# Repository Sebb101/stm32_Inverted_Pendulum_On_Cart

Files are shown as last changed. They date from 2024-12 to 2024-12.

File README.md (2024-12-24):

# Stm32_Inverted_Pendulum_On_Cart
Control systems learning project

Classic controls project: Inverted Pendulum On a Cart

Designed a custom stm32 board to handle data acquisition, motor control, and data out.

Tuned PID constants using matlab's System Identification and PID tuner applications

3D printed motor, encoder mounts, rail fixture and cart.

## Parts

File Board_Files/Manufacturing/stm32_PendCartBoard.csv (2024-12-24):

Source: | C:\Users\jasev\OneDrive\Desktop\KiCad Designs\KiCad_Personal\stm32_PendCartBoard\stm32_PendCartBoard.kicad_sch
Date: | 6/3/2023 7:27:07 PM
Tool: | Eeschema (6.0.11)
Generator: | C:\Program Files\KiCad\6.0\bin\scripting\plugins/bom_csv_grouped_by_value_with_fp.py
Component Count: | 45
Ref | Qnty | Value | Cmp name | Footprint | Description | Vendor
C1, C2, | 2 | 22u | C | Capacitor_SMD:C_0805_2012Metric | Unpolarized capacitor
C3, | 1 | 10u | C | Capacitor_SMD:C_0603_1608Metric | Unpolarized capacitor
C4, C5, C6, C7, C11, | 5 | 100n | C | Capacitor_SMD:C_0402_1005Metric | Unpolarized capacitor
C8, | 1 | 10n | C | Capacitor_SMD:C_0402_1005Metric | Unpolarized capacitor
C9, C10, | 2 | 1u | C | Capacitor_SMD:C_0402_1005Metric | Unpolarized capacitor
C12, C13, | 2 | 10p | C | Capacitor_SMD:C_0402_1005Metric | Unpolarized capacitor
C14, C16, | 2 | 0.1u | C | Capacitor_SMD:C_0805_2012Metric | Unpolarized capacitor
C15, C17, | 2 | 10u | C | Capacitor_SMD:C_0805_2012Metric | Unpolarized capacitor
D1, | 1 | RED | LED | LED_SMD:LED_0603_1608Metric | Light emitting diode
D2, | 1 | BLUE | LED | LED_SMD:LED_0603_1608Metric | Light emitting diode
FB1, | 1 | 120R | FerriteBead | Inductor_SMD:L_0603_1608Metric | Ferrite bead
H1, H2, H3, H4, | 4 | MountingHole | MountingHole | MountingHole:MountingHole_2.2mm_M2 | Mounting Hole without connection
J1, | 1 | PWR | Conn_01x02_Male | Connector_PinHeader_2.54mm:PinHeader_1x02_P2.54mm_Vertical | Generic connector, single row, 01x02, script generated (kicad-library-utils/schlib/autogen/connector/)
J2, | 1 | GPIO | Conn_01x04_Male | Connector_PinHeader_2.54mm:PinHeader_1x04_P2.54mm_Vertical | Generic connector, single row, 01x04, script generated (kicad-library-utils/schlib/autogen/connector/)
J3, | 1 | USB_B_Micro | USB_B_Micro | Connector_USB:USB_Micro-B_Wuerth_629105150521 | USB Micro Type B connector
J4, | 1 | MotorOut | Conn_01x04_Male | Connector_PinHeader_2.54mm:PinHeader_1x04_P2.54mm_Vertical | Generic connector, single row, 01x04, script generated (kicad-library-utils/schlib/autogen/connector/)
J5, | 1 | DEBUG | Conn_01x02_Male | Connector_PinHeader_2.54mm:PinHeader_1x02_P2.54mm_Vertical | Generic connector, single row, 01x02, script generated (kicad-library-utils/schlib/autogen/connector/)
J6, | 1 | 5Vin | Conn_01x02_Male | Connector_PinHeader_2.54mm:PinHeader_1x02_P2.54mm_Vertical | Generic connector, single row, 01x02, script generated (kicad-library-utils/schlib/autogen/connector/)
J7, | 1 | BAT 12V+ | Conn_01x02_Male | Connector_PinHeader_2.54mm:PinHeader_1x02_P2.54mm_Vertical | Generic connector, single row, 01x02, script generated (kicad-library-utils/schlib/autogen/connector/)
J8, | 1 | UART | Conn_01x04_Male | Connector_PinHeader_2.54mm:PinHeader_1x04_P2.54mm_Vertical | Generic connector, single row, 01x04, script generated (kicad-library-utils/schlib/autogen/connector/)
J9, | 1 | I2C | Conn_01x04_Male | Connector_PinHeader_2.54mm:PinHeader_1x04_P2.54mm_Vertical | Generic connector, single row, 01x04, script generated (kicad-library-utils/schlib/autogen/connector/)
J10, | 1 | PWR | Conn_01x04_Male | Connector_PinHeader_2.54mm:PinHeader_1x04_P2.54mm_Vertical | Generic connector, single row, 01x04, script generated (kicad-library-utils/schlib/autogen/connector/)
R1, R3, R4, R5, R6, | 5 | 1k5 | R | Resistor_SMD:R_0402_1005Metric | Resistor
R2, | 1 | 10k | R | Resistor_SMD:R_0402_1005Metric | Resistor
SW1, | 1 | SW_SPDT | SW_SPDT | Button_Switch_SMD:SW_SPDT_PCM12 | Switch, single pole double throw
U1, | 1 | AMS1117-3.3 | AMS1117-3.3 | Package_TO_SOT_SMD:SOT-223-3_TabPin2 | 1A Low Dropout regulator, positive, 3.3V fixed output, SOT-223
U2, | 1 | STM32F103C8T6 | STM32F103C8Tx | Package_QFP:LQFP-48_7x7mm_P0.5mm | ARM Cortex-M3 MCU, 64KB flash, 20KB RAM, 72MHz, 2-3.6V, 37 GPIO, LQFP-48
U3, | 1 | TB6612FNG | TB6612FNG | Package_SO:SSOP-24_5.3x8.2mm_P0.65mm | Driver IC for Dual DC motor, SSOP-24
Y1, | 1 | 16MHz | Crystal_GND24 | Crystal:Crystal_SMD_3225-4Pin_3.2x2.5mm | Four pin crystal, GND on pins 2 and 4

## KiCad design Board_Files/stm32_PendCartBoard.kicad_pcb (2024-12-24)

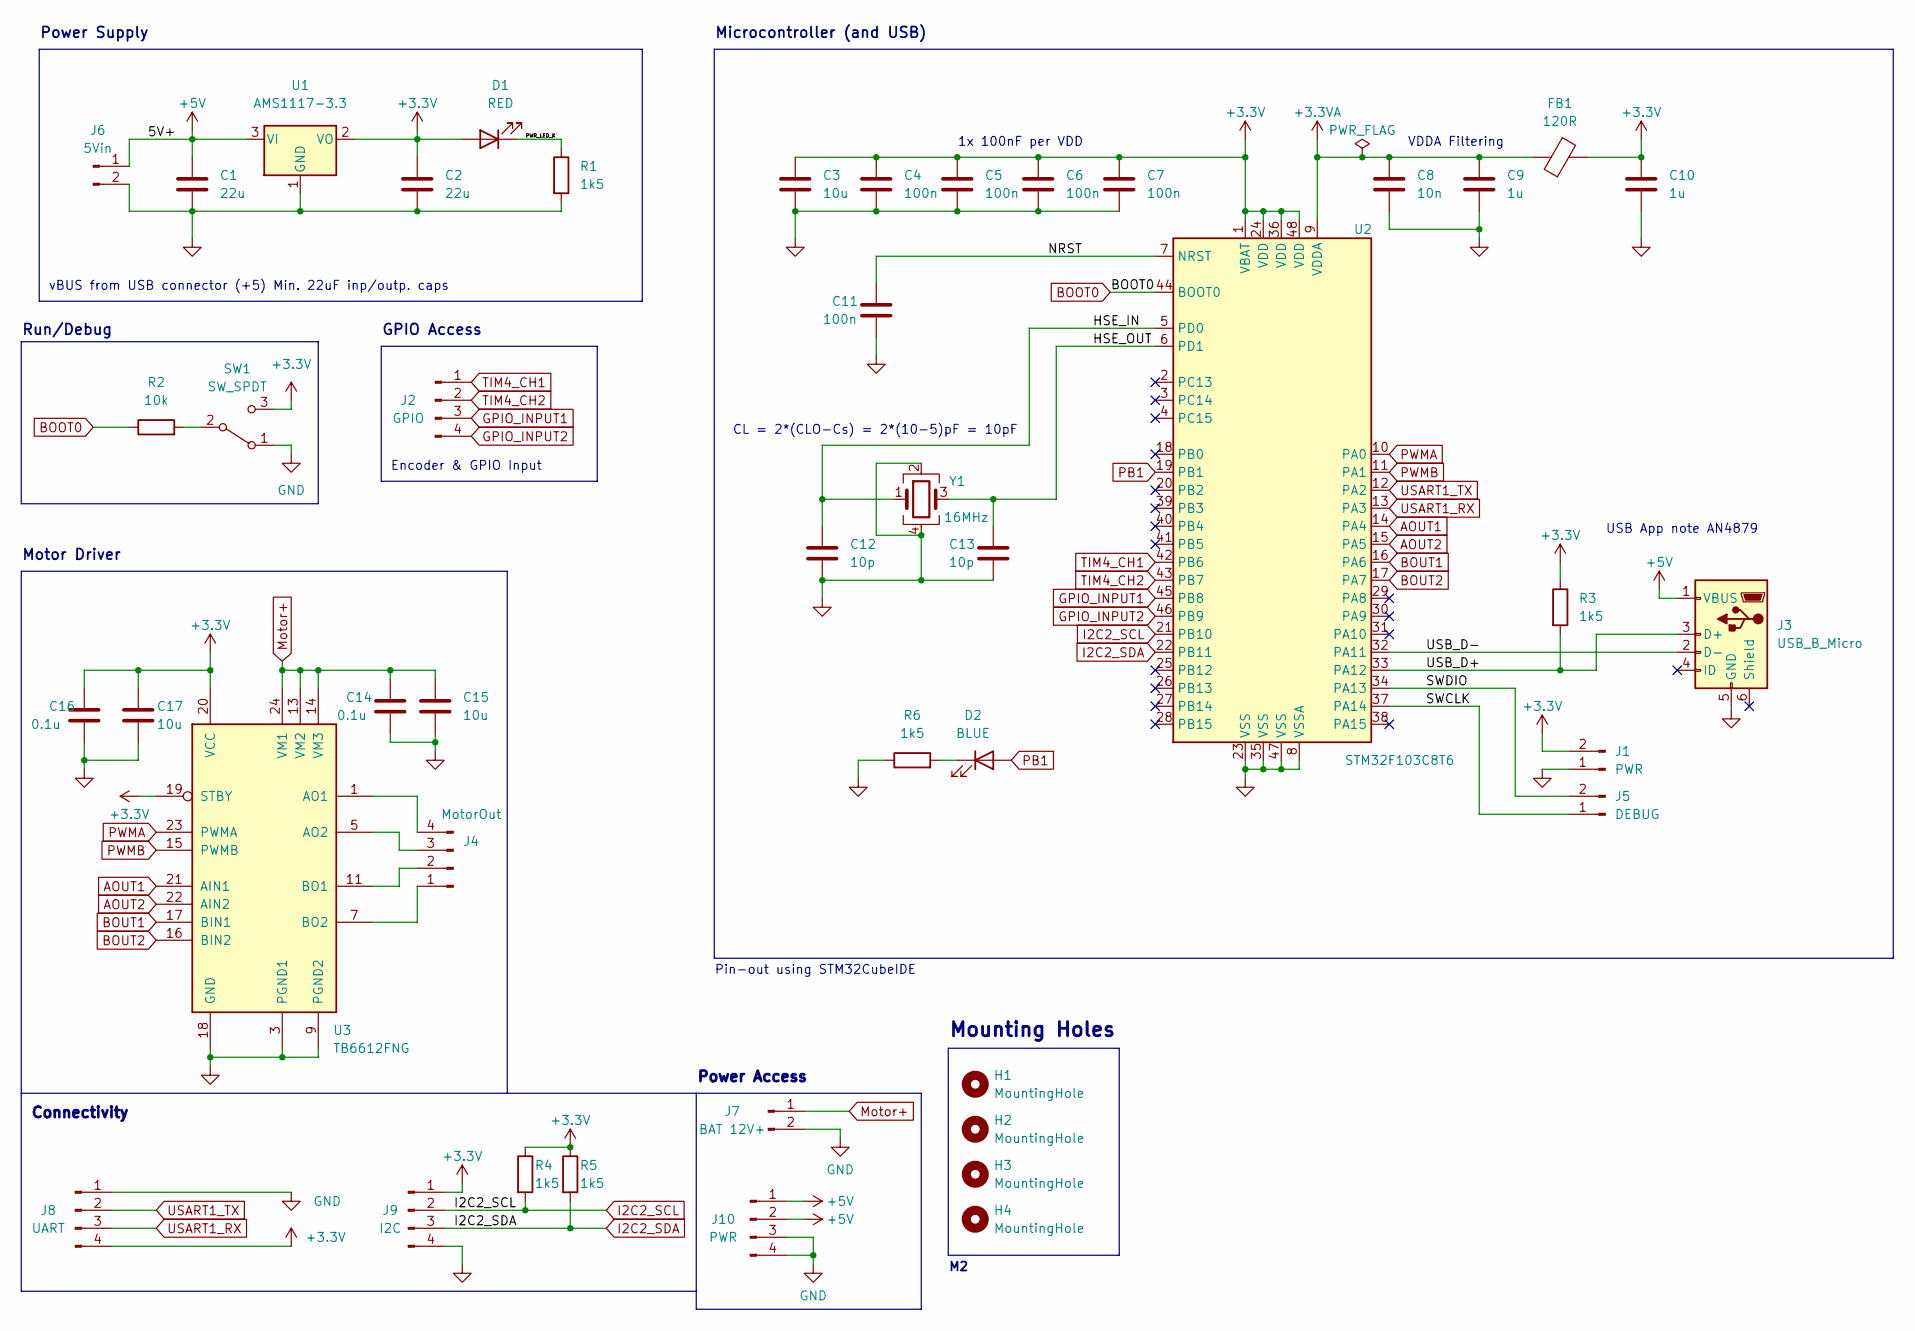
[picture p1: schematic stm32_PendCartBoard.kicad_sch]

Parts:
C1, C2: 22u; C_0805_2012Metric
C3: 10u; C_0603_1608Metric
C4, C5, C6, C7, C11: 100n; C_0402_1005Metric
C8: 10n; C_0402_1005Metric
C9, C10: 1u; C_0402_1005Metric
C12, C13: 10p; C_0402_1005Metric
C14, C16: 0.1u; C_0805_2012Metric
C15, C17: 10u; C_0805_2012Metric
D1: RED; LED_0603_1608Metric
D2: BLUE; LED_0603_1608Metric
FB1: 120R; L_0603_1608Metric
H1, H2, H3, H4: MountingHole; MountingHole_2.2mm_M2
J1: PWR; PinHeader_1x02_P2.54mm_Vertical
J2: GPIO; PinHeader_1x04_P2.54mm_Vertical
J3: USB_B_Micro; USB_Micro-B_Wuerth_629105150521
J4: MotorOut; PinHeader_1x04_P2.54mm_Vertical
J5: DEBUG; PinHeader_1x02_P2.54mm_Vertical
J6: 5Vin; PinHeader_1x02_P2.54mm_Vertical
J7: BAT 12V+; PinHeader_1x02_P2.54mm_Vertical
J8: UART; PinHeader_1x04_P2.54mm_Vertical
J9: I2C; PinHeader_1x04_P2.54mm_Vertical
J10: PWR; PinHeader_1x04_P2.54mm_Vertical
R1, R3, R4, R5, R6: 1k5; R_0402_1005Metric
R2: 10k; R_0402_1005Metric
SW1: SW_SPDT; SW_SPDT_PCM12
U1: AMS1117-3.3; SOT-223-3_TabPin2
U2: STM32F103C8T6; LQFP-48_7x7mm_P0.5mm
U3: TB6612FNG; SSOP-24_5.3x8.2mm_P0.65mm
Y1: 16MHz; Crystal_SMD_3225-4Pin_3.2x2.5mm

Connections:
+3.3V: C2.1, C3.1, C4.1, C5.1, C6.1, C7.1, C10.1, C16.1, C17.1, D1.2 (A), FB1.2, J1.2, J8.4, J9.1, R3.1, R4.1, R5.1, SW1.3 (C), U1.2 (VO), U2.1 (VBAT), U2.24 (VDD), U2.36 (VDD), U2.48 (VDD), U3.19 (STBY), U3.20 (VCC)
+3.3VA: C8.1, C9.1, FB1.1, U2.9 (VDDA)
+5V: C1.1, J3.1 (VBUS), J6.1, J10.1, J10.2, U1.3 (VI)
/HSE_IN: C12.1, U2.5 (PD0), Y1.1
/HSE_OUT: C13.1, U2.6 (PD1), Y1.3
/NRST: C11.1, U2.7 (NRST)
/PWR_LED_K: D1.1 (K), R1.1
/SWCLK: J5.1, U2.37 (PA14)
/SWDIO: J5.2, U2.34 (PA13)
/USB_D+: J3.3 (D+), R3.2, U2.33 (PA12)
/USB_D-: J3.2 (D-), U2.32 (PA11)
AOUT1: U2.14 (PA4), U3.21 (AIN1)
AOUT2: U2.15 (PA5), U3.22 (AIN2)
BOOT0: R2.1, U2.44 (BOOT0)
BOUT1: U2.16 (PA6), U3.17 (BIN1)
BOUT2: U2.17 (PA7), U3.16 (BIN2)
GND: C1.2, C2.2, C3.2, C4.2, C5.2, C6.2, C7.2, C8.2, C9.2, C10.2, C11.2, C12.2, C13.2, C14.2, C15.2, C16.2, C17.2, J1.1, J3.5 (GND), J6.2, J7.2, J8.1, J9.4, J10.3, J10.4, R1.2, R6.1, SW1.1 (A), U1.1 (GND), U2.8 (VSSA), U2.23 (VSS), U2.35 (VSS), U2.47 (VSS), U3.3 (PGND1), U3.4 (PGND1), U3.9 (PGND2), U3.10 (PGND2), U3.18 (GND), Y1.2, Y1.4
GPIO_INPUT1: J2.3, U2.45 (PB8)
GPIO_INPUT2: J2.4, U2.46 (PB9)
I2C2_SCL: J9.2, R4.2, U2.21 (PB10)
I2C2_SDA: J9.3, R5.2, U2.22 (PB11)
Motor+: C14.1, C15.1, J7.1, U3.13 (VM2), U3.14 (VM3), U3.24 (VM1)
unnamed: D2.1 (K), R6.2
unnamed: J4.1, U3.7 (BO2), U3.8 (BO2)
unnamed: J4.2, U3.11 (BO1), U3.12 (BO1)
unnamed: J4.3, U3.5 (AO2), U3.6 (AO2)
unnamed: J4.4, U3.1 (AO1), U3.2 (AO1)
unnamed: R2.2, SW1.2 (B)
PB1: D2.2 (A), U2.19 (PB1)
PWMA: U2.10 (PA0), U3.23 (PWMA)
PWMB: U2.11 (PA1), U3.15 (PWMB)
TIM4_CH1: J2.1, U2.42 (PB6)
TIM4_CH2: J2.2, U2.43 (PB7)
USART1_RX: J8.3, U2.13 (PA3)
USART1_TX: J8.2, U2.12 (PA2)

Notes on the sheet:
Microcontroller (and USB)
VDDA Filtering
Motor Driver
Mounting Holes
GPIO Access
Power Access
Connectivity
Pin-out using STM32CubeIDE
Run/Debug
Encoder & GPIO Input
1x 100nF per VDD
USB App note AN4879
Power Supply
CL = 2*(CLO-Cs) = 2*(10-5)pF = 10pF
vBUS from USB connector (+5) Min. 22uF inp/outp. caps

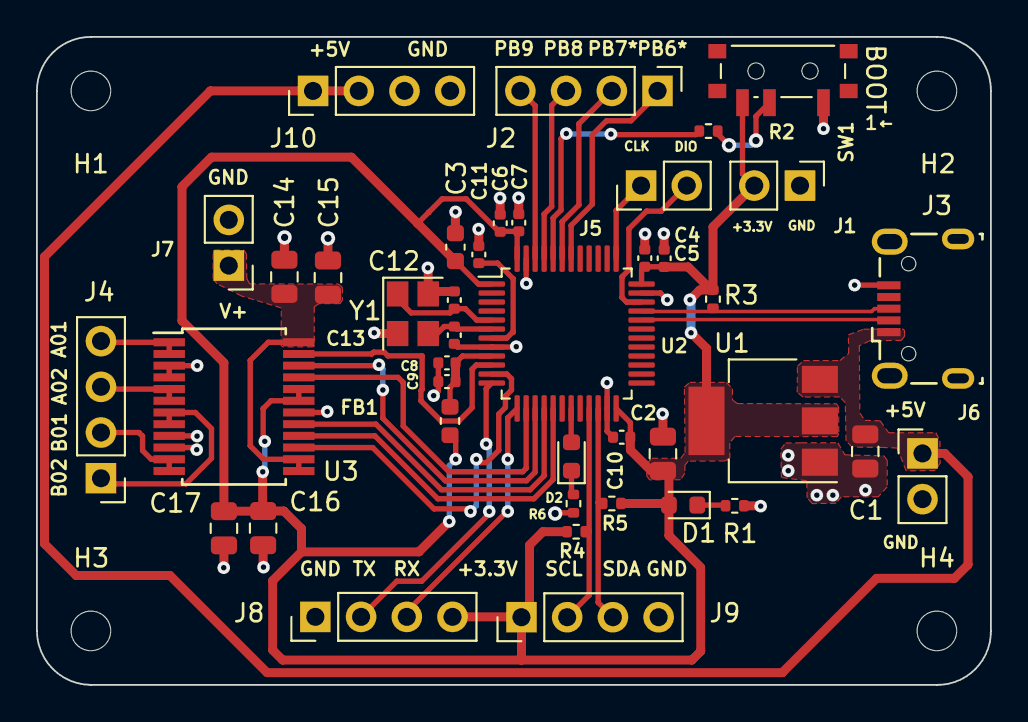
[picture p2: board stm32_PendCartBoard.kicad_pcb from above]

Board: 2 copper layers, 53.0 x 36.0 mm, 45 parts (0 on the bottom side), 35 nets.

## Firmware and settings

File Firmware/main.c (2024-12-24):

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
/* Includes ------------------------------------------------------------------*/
#include "main.h"
#include "usb_device.h"

/* USER CODE BEGIN Includes */
#include "pid.h"
#include "usbd_cdc_if.h"
#include "string.h"
#include "math.h"
/* USER CODE END Includes */

/* USER CODE BEGIN PD */
#define derivative_sample_size 5 //derivative sample size
#define sample_size 50 //sample size for data acquisition

/* USER CODE END PD */

I2C_HandleTypeDef hi2c2;

TIM_HandleTypeDef htim2;
TIM_HandleTypeDef htim4;
DMA_HandleTypeDef hdma_tim2_ch1;

UART_HandleTypeDef huart2;

void SystemClock_Config(void);
static void MX_GPIO_Init(void);
static void MX_DMA_Init(void);
static void MX_I2C2_Init(void);
static void MX_TIM2_Init(void);
static void MX_TIM4_Init(void);
static void MX_USART2_UART_Init(void);
/* USER CODE BEGIN PFP */

//encoder functions
void init_hardware_timer_version(void);
///void init_interrupt_version(void);

// Error function
static inline void calculate_error();
static inline void moving_average_derivative_calculation();

// end of copy and paste code

/* USER CODE END PFP */

/* USER CODE BEGIN 0 */

// loop counter
static long loop_count = 0;

// USB Send
struct XL_Data{
  double ang,volt;
}usb_data;

// SIN WAVE variables
double a = 100; // amplitude ; a / 100 * 12 = Motor Voltage
double F1 = 2.001; // Frequency 1
double Fmin = 2; // Min Frequency
double Fmax = 13; // Max Frequency
double t = 0;
double Fs = 333.3; // Sample Frequency
double MAXPHASE = 65536;
double iphase = 0;
double delta = 0;

// Rotary Pendulum Encoder Variables
double angle = 0; //0 == down position ; 3.14 == up position
double angular_velocity = 0;
double previous_angle = 0;
//float radian_angle = 3.14;

// Rotary Cart Encoder Variables
int cartcounter = 0;
float cartpos = 0;

const float angle_radians_factor = 0.002617993; // Rotary encoder rotation 2*pi == 2400 ticks
const float radians_meters_factor = 0.08; // Rotary encoder radius is 0.08 m

//moving average arrays
double angular_velocity_ma[derivative_sample_size];
double oldest_angular_velocity;



//set point variables
double x_desired = 0.0;
double xdot_desired = 0.0;
double theta_desired = 3.14159265;
double thetadot_desired = 0;

//error variables
double x_error = 0;
double xdot_error = 0;
double theta_error = 0;
double thetadot_error = 0;

//time variables
double current_time;
double previous_time;
double dt = 0;


// Motor Variables
double PIDvalue = 0;
double mtr_volt = 0;
static int minimum_motor_feedback = 0; //minimum PWM signal to move motor
int motorDir = 0;
int motorSpeed=0;

void init_hardware_timer_version(void)
{
 RCC->APB2ENR |= RCC_APB2ENR_AFIOEN | RCC_APB2ENR_IOPBEN;
 RCC->APB1ENR |= RCC_APB1ENR_TIM4EN; //AFIO might not even be needed?

 //GPIO must be input floating which is default so no code to write for that

 // value to count up to : 16 bit so max is 0xFFFF = 65535
 //TIM4->ARR = 0xFFFF;
 TIM4->ARR = 0x0960;

 //per datasheet instructions
 TIM4->CCMR1 |= (TIM_CCMR1_CC1S_0 | TIM_CCMR1_CC2S_0 );  //step 1 and 2
 TIM4->CCER &= ~(TIM_CCER_CC1P | TIM_CCER_CC2P);  // step 3 and 4
 TIM4->SMCR |= TIM_SMCR_SMS_0 | TIM_SMCR_SMS_1;   //step 5
 TIM4->CR1 |= TIM_CR1_CEN ;     //step 6
}


void init_interrupt_version(void)
{
 RCC->APB2ENR |= RCC_APB2ENR_AFIOEN;
 RCC->APB2ENR |= RCC_APB2ENR_IOPBEN;
 EXTI->IMR |= 1<<8; //enable interrupt on EXTI-8
 //EXTI->IMR |= 1<<9; //enable interrupt on EXTI-9
 NVIC_EnableIRQ(EXTI9_5_IRQn); //enable the IRQ line that corresponds to EXT-5 to 9
 EXTI->RTSR |= 1<<8; //enable rising edge interrupt to EXTI 8
 //EXTI->FTSR |= 1<<9; //enable falling edge interrupt to EXTI 9
 AFIO->EXTICR[3] |= 1; // set interrupt EXTI 8 to be on port B
 //AFIO->EXTICR[3] |= 1<<4; // set interrupt EXTI 9 to be on port B
}

static inline void calculate_error(){
	//calculate errors
	theta_error = angle - theta_desired;
	thetadot_error = angular_velocity - thetadot_desired;
}

static inline void moving_average_derivative_calculation(){
	//moving average for derivative calculations

	oldest_angular_velocity = angular_velocity_ma[loop_count % derivative_sample_size];
	angular_velocity_ma[loop_count % derivative_sample_size] = (angle - previous_angle) / (dt);
	angular_velocity += ((angular_velocity_ma[loop_count % derivative_sample_size] - oldest_angular_velocity) / derivative_sample_size);

}
//struct XL_Data * data


void sendusbData(double timeinterval,double pend_pos, double mtr_volt){
    uint8_t bufferOne[50];
    //uint8_t *bufferOne = "this is a testr\r\n";
    sprintf(bufferOne, "%0.7f,%0.7f,%0.7f\r\n", timeinterval, pend_pos, mtr_volt);
    CDC_Transmit_FS( (uint8_t *)bufferOne, strlen(bufferOne));

}

double hz_to_delta( double hz )
{
    return hz/Fs;
}

double sample_phase( double phase )
{
    return a*sin(phase*M_PI );
}


/* USER CODE END 0 */

/**
  * @brief  The application entry point.
  * @retval int
  */
int main(void)
{
  /* MCU Configuration--------------------------------------------------------*/

  /* Reset of all peripherals, Initializes the Flash interface and the Systick. */
  HAL_Init();

  /* Configure the system clock */
  SystemClock_Config();

  /* Initialize all configured peripherals */
  MX_GPIO_Init();
  MX_DMA_Init();
  MX_I2C2_Init();
  MX_TIM2_Init();
  MX_TIM4_Init();
  MX_USART2_UART_Init();
  MX_USB_DEVICE_Init();
  /* USER CODE BEGIN 2 */

  // PWMA - MotorA PWM setup
  // Duty% = CCR / COUNTERPERIOD
  HAL_TIM_PWM_Start(&htim2,TIM_CHANNEL_1);

  // Encoder timer input
  init_hardware_timer_version();

  /* USER CODE END 2 */

  /* Infinite loop */
  /* USER CODE BEGIN WHILE */
  while (1)
  {
	  // Test board LED PB1
	  //HAL_GPIO_WritePin(GPIOB, GPIO_PIN_1, 1);
	  //HAL_Delay(1000);
	  //HAL_GPIO_WritePin(GPIOB, GPIO_PIN_1, 0);
	  //HAL_Delay(1000);


	  //Get time
	  //current_time = (HAL_GetTick() );
	  current_time = (HAL_GetTick() )* 0.001;
	  dt = current_time - previous_time;
	  //HAL_Delay(5);

	  // Send Data via USB
	  sendusbData(dt,angle,PIDvalue);
	  //sendusbData(dt,angle,mtr_volt);
	  HAL_Delay(2);

	  //Encoder Pendulum Angle
	  angle = (TIM4->CNT)*angle_radians_factor;

	  // Encoder Cart Position
	  cartpos = (cartcounter)*(0.00007);

	  // Calculate Angular Velocity
	  //moving_average_derivative_calculation();
	  angular_velocity = (angle - previous_angle) / (dt);

	  // Error between set point and measurement
	  calculate_error();

	  // Motor  Control ~~~~~~~~~~~~~~~~~~~~~~~~~~~~~~~~~~~~~~~~~~~~~~~~~~~~

	  // PID Controller
	  PIDvalue = (PID(&theta_error, &dt, &angle, &previous_angle));

	  // Save previous values
	  previous_time = current_time;
	  previous_angle = angle;

	  // Sin Wave Input (F1 = angular velocity)
	  //PIDvalue = a*sin(F1*t);

	  // Cont. Freq changing Sin Wave Input
	  /*
	  if (t>=5 && F1 >= Fmin && F1 <= Fmax){
	  delta = hz_to_delta( F1 );
	  PIDvalue = sample_phase( iphase += delta );
	  F1+=0.0005;
	  }else{
		  PIDvalue = 0;
	  }
	*/
	  // Step function 1sec, 2sec & 3sec
	  /*
	  if (t>=5 && t<=5.03){
		  PIDvalue+=10;
	  }
	  if (t>=5.5 && t<=5.53){
		  PIDvalue-=10;
	  }
	*/

	  // Motor Speed & Direction Code ~~~~~~~~~~~~~~~~~~~~~~~~~~~~~~~~~~~~~~~~

	  if (PIDvalue < minimum_motor_feedback && PIDvalue > 0){
		  // Set motor PWM to min signal & move right
		  motorSpeed = minimum_motor_feedback;
		  HAL_GPIO_WritePin(GPIOA, GPIO_PIN_4, 0);
		  HAL_GPIO_WritePin(GPIOA, GPIO_PIN_5, 1);
		  motorDir=1; //CW & Right = 1 ; CCW & Left = 0
	  }
	  else if (PIDvalue > minimum_motor_feedback && PIDvalue > 0) {
		  // Set motor PWM to PIDvalue & move right
		  motorSpeed = PIDvalue;
		  if (PIDvalue > 100){
			  motorSpeed = 100;
		  }
		  HAL_GPIO_WritePin(GPIOA, GPIO_PIN_4, 0);
		  HAL_GPIO_WritePin(GPIOA, GPIO_PIN_5, 1);
		  motorDir=1;
	  }
	  else if (PIDvalue > -minimum_motor_feedback && PIDvalue < 0) {
		  // Set motor PWM to min signal & move left
		  motorSpeed = minimum_motor_feedback;
		  HAL_GPIO_WritePin(GPIOA, GPIO_PIN_4, 1);
		  HAL_GPIO_WritePin(GPIOA, GPIO_PIN_5, 0);
		  motorDir=0;
	  }
	  else if (PIDvalue < -minimum_motor_feedback && PIDvalue < 0) {
		  // Set motor PWM to min signal & move left
		  motorSpeed = -PIDvalue;
		  if (PIDvalue < -100){
			  motorSpeed = 100;
		  }
		  HAL_GPIO_WritePin(GPIOA, GPIO_PIN_4, 1);
		  HAL_GPIO_WritePin(GPIOA, GPIO_PIN_5, 0);
		  motorDir=0;
	  }
	  else if (PIDvalue == 0){
		  HAL_GPIO_WritePin(GPIOA, GPIO_PIN_4, 0);
		  HAL_GPIO_WritePin(GPIOA, GPIO_PIN_5, 0);
	  }


	  // MotorSpeed value between 25-100
	  TIM2->CCR1 = motorSpeed;
	  mtr_volt = (motorSpeed / 100.0) * 12;

	  t+=0.003;


    /* USER CODE END WHILE */

    /* USER CODE BEGIN 3 */
  }
  /* USER CODE END 3 */
}

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

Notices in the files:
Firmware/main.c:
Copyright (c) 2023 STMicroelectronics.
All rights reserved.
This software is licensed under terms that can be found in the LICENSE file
